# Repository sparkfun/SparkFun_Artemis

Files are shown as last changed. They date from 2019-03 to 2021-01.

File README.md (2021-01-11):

SparkFun Artemis
============================

SparkFun Artemis (https://www.sparkfun.com/products/15332)

[*SparkFun Artemis Module (WRL-15484)*](https://www.sparkfun.com/products/15484)

The Artemis Module from SparkFun is the first product to bridge the market between hobbyists and consumer products. We've exhaustively packaged all the power of a modern microcontroller into a module that is both extremely easy to use but is mass-market ready. 

The flexibility of the Artemis module starts with our [Arduino core](https://github.com/sparkfun/Arduino_Apollo3). You can program and use the Artemis module just like you would an Uno or any other Arduino. Time to first blink is just 5 minutes away! We built the core from the ground up, making it fast and as light weight as possible. 

Next is the module itself. Measuring 10x15mm the Artemis module has all the support circuitry you need to use the fantastic Apollo3 processor in your next project. We're proud to say the SparkFun Artemis module is the first open source hardware module with the design files freely and easily available here (on this repo). We've carefully designed the module so that routing to the module can be done with low-cost 2-layer PCBs with 8mil trace/space. Addtionally, we've released four open-source-hardware example products that act as a starting point for your product.

Made in the USA at SparkFun's Boulder production line the Artemis module is designed for consumer grade products. This truly differentiates the Artemis from its Arduino brethren. Ready to scale your product? The Artemis will grow with you beyond the Uno footprint and Arduino IDE. Tape and reel quantities or the Artemis module are available in addition, the Artemis has an advanced HAL (hardware abstraction layer) allowing users to push the modern Cortex-M4F architecture to its limit. 

This repo contains the design files for the 4-layer PCB. This design is pretty reliant on sophisticated manufacturing tools. We *do not* recommend that you order PCBs and attempt to hand stencil or hand place these components. We hope you can learn from our work and share what you've learned for the next generation of engineers and hackers. 

Repository Contents
-------------------
* **/Artwork** - SVG of laser etching on RF shield
* **/Bootloader** - Tools for loading the Artemis with Ambiq's secure bootloader
* **/Documentation** - Data sheets, additional product information
* **/Hardware** - Eagle design files (.brd, .sch)

Documentation
-------------------
* **[Designing with the SparkFun Artemis](https://learn.sparkfun.com/tutorials/designing-with-the-sparkfun-artemis)** - Layout and design considerations when using the Artemis module.
* **[Artemis Development with Arduino](https://learn.sparkfun.com/tutorials/artemis-development-with-arduino)** - Introduction to the Arduino core for the Artemis Module.
* **[Using SparkFun Edge Board with Ambiq Apollo3 SDK](https://learn.sparkfun.com/tutorials/using-sparkfun-edge-board-with-ambiq-apollo3-sdk)** - Getting set up with the Apollo3 Software Development Kit.

License Information
-------------------

This product is _**open source**_! 

Please review the LICENSE.md file for license information. 

If you have any questions or concerns on licensing, please contact techsupport@sparkfun.com.

Please use, reuse, and modify these files as you see fit. Please maintain attribution to SparkFun Electronics and release any derivative under the same license.

Distributed as-is; no warranty is given.

- Your friends at SparkFun.

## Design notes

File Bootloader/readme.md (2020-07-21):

Artemis Bootloader
==========================

The Artemis module is loaded with two bootloaders: the ASB and SVL. The Ambiq Secure Boot Loader (ASB) resides from 0x00 to 0xC000. This bootloader is physically part of the IC and is configured using the info0 registers. At power up, if the ASB is not activated, it jumps to 0xC000. The SparkFun Variable Bootloader (SVL) resides at 0xC000 and will wait for an incoming serial character. If a character is received, the baud rate will be auto-detected, the SVL will load new code, then jump to the new user code starting at 0x10000. The SVL times out after 50ms.

This directory contains the various binaries that are programmed onto each Artemis module:

* info0_artemis_47_115200.bin - Sets the Ambiq Secure Bootloader (ASB) to 115200bps with boot pin on 47
* artemis_svl.bin - the SparkFun Variable Loader (SVL), starts at 0xC000
* example1_blink.ino.bin - An example sketch to blink the LED. This shows code has been loaded but will be overwritten with new sketches.

The code for the bootloader can be found in the [Apollo3 BSP](https://github.com/sparkfun/SparkFun_Apollo3_AmbiqSuite_BSPs/tree/master/common/examples/artemis_svl).

The bootloader for the Artemis can be upgraded via Arduino using [these instructions](https://learn.sparkfun.com/tutorials/designing-with-the-sparkfun-artemis/all#troubleshooting). It can also be upgraded using the [Artemis Firmware Upload GUI](https://github.com/sparkfun/Artemis-Firmware-Upload-GUI).

The ASB is configured based on the documents from Ambiq (Ambiq calls it the secure bootloader or SBL). See \AmbiqSuite-Rel2.x.x\docs\secure_bootloader\ for how to modify the info0 image. 

* Run the bootloader at 921600bps: --u0 0x1C299c0
* Currently pin 47 is used for BOOTLOAD: --gpio 0x2f
* Bootloader to check if BOOTLOAD pin is high (not low): --gpiolvl 1
* Trim timeout to 2500ms: --wTO 2500

This was used for Artemis v10 module that used pin 47 for boot:

    create_info0.py --valid 1 info0_artemis_47 --pl 1 --u0 0x1C200c0 --u1 0xFFFF3031 --u2 0x2 --u3 0x0 --u4 0x0 --u5 0x0 --main 0xC000 --gpio 0x2f --version 0 --wTO 2500 --gpiolvl 1

We load a conservative 115200bps image into the Ambiq ASB section so that future updates can be applied. The SparkFun Variable Loader is a variable bootloader capable of operating from 115200bps to 921600bps.

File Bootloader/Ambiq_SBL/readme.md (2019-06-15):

Artemis Bootloader
==========================

The Artemis module is loaded with two bootloaders: the SBL and ABL. The Ambiq Secure Boot Loader (SBL) resides from 0x00 to 0xC000. This bootloader is physically part of the IC and is configured using the info0 registers. At power up, if the SBL is not activated, it jumps to 0xC000. The SparkFun Artemis Bootloader (ABL) resides at 0xC000 and will broadcast a character at POR. If the correct response is received, the ABL will negotiate a bootload speed, then jump to user code starting at 0x10000. The ABL times out after 50ms.

This directory contains the various binaries that are programmed onto each Artemis module:

* info0_artemis_47_115200.bin - Sets the SBL to 115200bps with boot pin on 47
* Artemis_Bootloader_v10.bin - the ABL, starts at 0xC000
* example1_blink.ino.bin - An example sketch to blink the LED. This shows code has been loaded but will be overwritten with new sketches.

For more information on the Artemis Bootloader see the Artemis Bootloader sketch in the SparkFun_BL directory in this repo.

The SBL is configured based on the documents from Ambiq. See \AmbiqSuite-Rel2.x.x\docs\secure_bootloader\ for how to modify the SBL/info0 image. 

* Run the bootloader at 921600bps: --u0 0x1C299c0
* Currently pin 47 is used for BOOTLOAD: --gpio 0x2f
* Bootloader to check if BOOTLOAD pin is high (not low): --gpiolvl 1
* Trim timeout to 2500ms: --wTO 2500

This was used for Artemis v10 module that used pin 47 for boot:

    create_info0.py --valid 1 info0_artemis_47 --pl 1 --u0 0x1C200c0 --u1 0xFFFF3031 --u2 0x2 --u3 0x0 --u4 0x0 --u5 0x0 --main 0xC000 --gpio 0x2f --version 0 --wTO 2500 --gpiolvl 1

We load a conservative 115200bps image into the Ambiq SBL section so that future updates can be applied. The SparkFun Artemis Bootloader is a variable bootloader capable of operating from 9600bps to 921600bps.

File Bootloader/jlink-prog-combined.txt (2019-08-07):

//connect to device
device AMA3B1KK-KBR
si SWD
speed 1000
r
sleep 10

//set C runtime environment
wreg MSP, 0x10000100

// erase info0
w4 0x10000000 0             // flash info instance
w4 0x10000004 0xd894e09e    // info 0 key
w4 0x10000008 0xFFFFFFFF    // clear return value
setPC 0x08000085            // call the ROM helper function flash_info_erase_from_sram
g
sleep 50
mem32 0x10000008 1          // dump return value for check

// program info0
w4 0x10000000 0             // flash info instance
w4 0x10000004 0             // offset
w4 0x10000008 0x800         // length in words
w4 0x1000000C 0xd894e09e    // info 0 key
w4 0x10000010 0xFFFFFFFF    // clear return value
loadbin info0_artemis_47_115200.bin 0x10001000     //load the info0 binary into sram
setPC 0x08000061            // call the ROM helper function flash_program_info_area_from_sram
g
sleep 50
mem32 0x10000010 1          // dump return value for check

loadbin artemis_svl.bin 0x0000C000     //load SVL into 0xC000 (end of Ambiq bootloader)

loadbin example1_blink.ino.bin 0x00010000     //load Blink after SVL

// perform software POI
w4 0x40000004 0x1B

// quit
qc

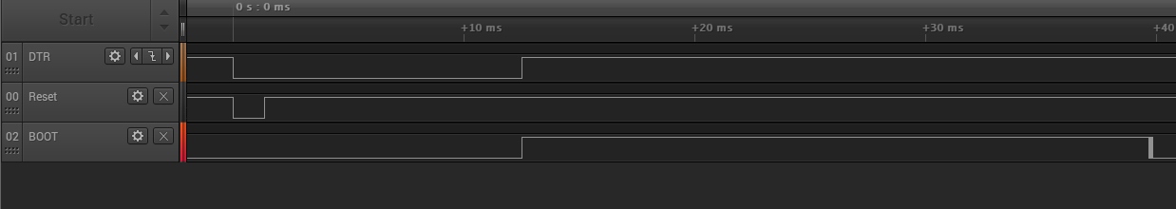
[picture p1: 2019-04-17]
Documents/Auto-Bootload Timing.jpg

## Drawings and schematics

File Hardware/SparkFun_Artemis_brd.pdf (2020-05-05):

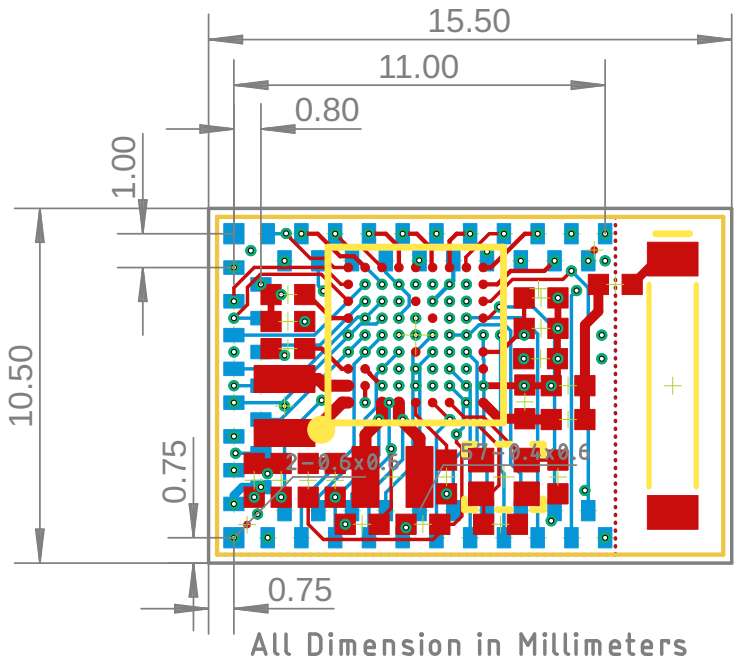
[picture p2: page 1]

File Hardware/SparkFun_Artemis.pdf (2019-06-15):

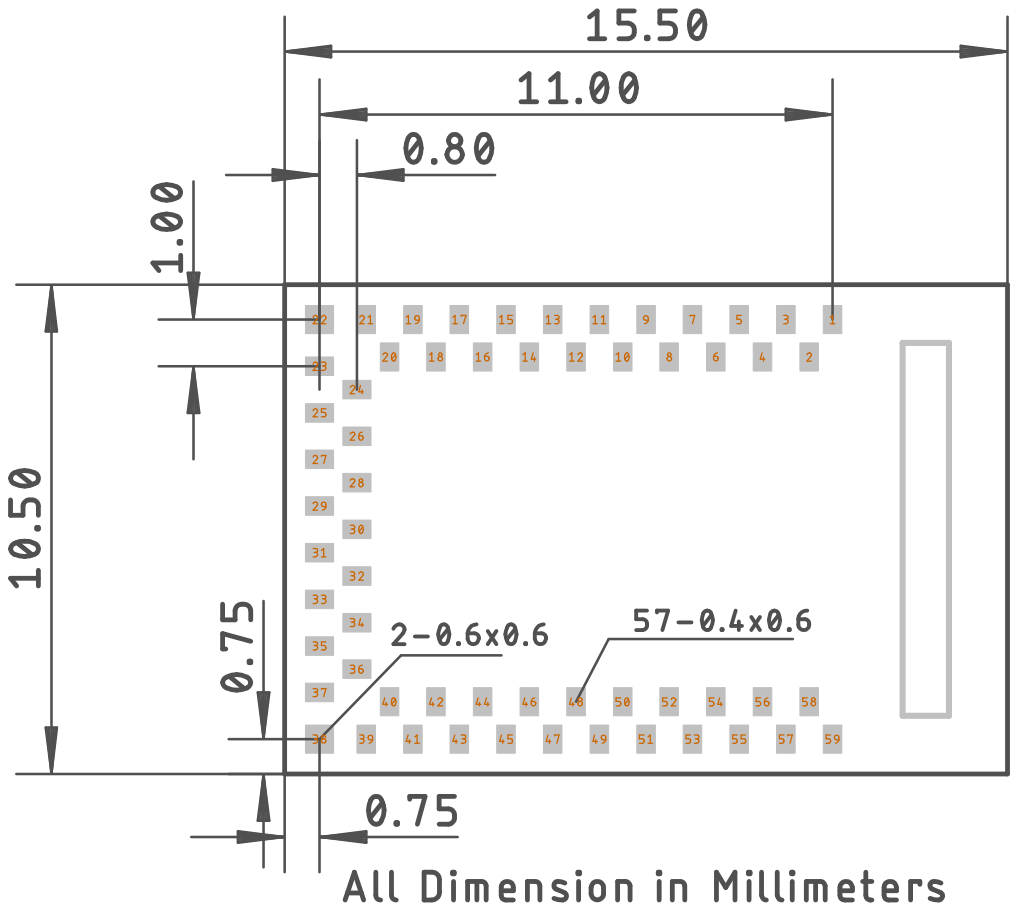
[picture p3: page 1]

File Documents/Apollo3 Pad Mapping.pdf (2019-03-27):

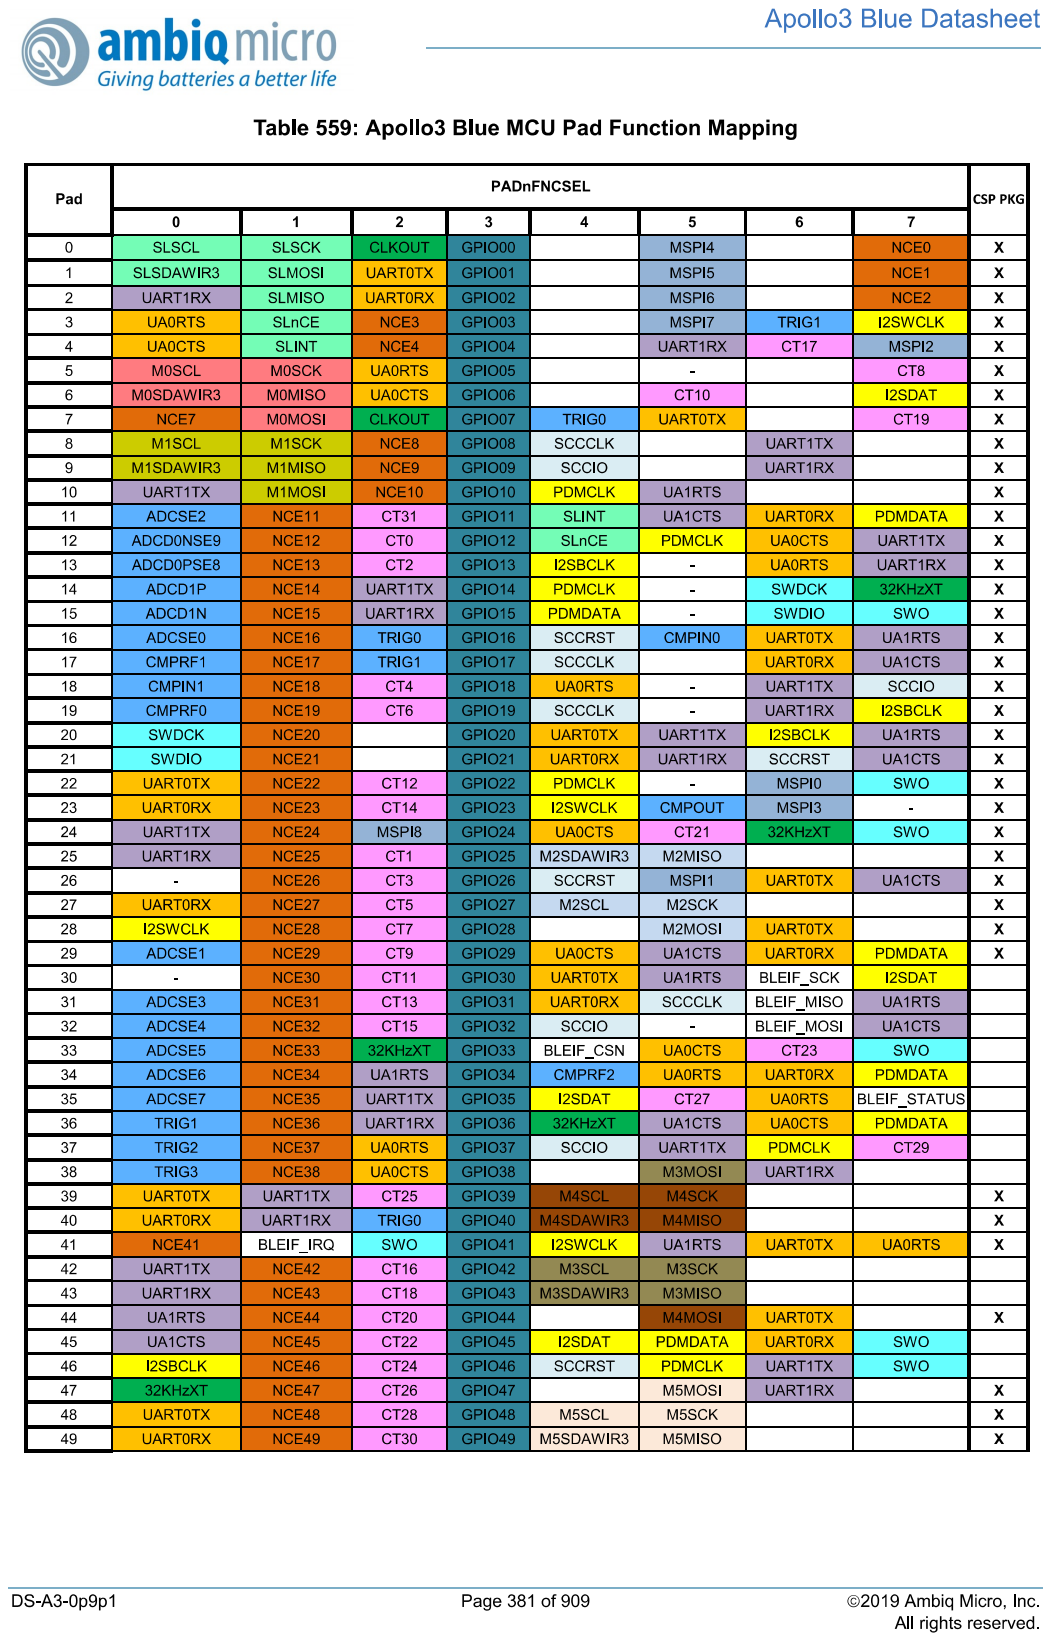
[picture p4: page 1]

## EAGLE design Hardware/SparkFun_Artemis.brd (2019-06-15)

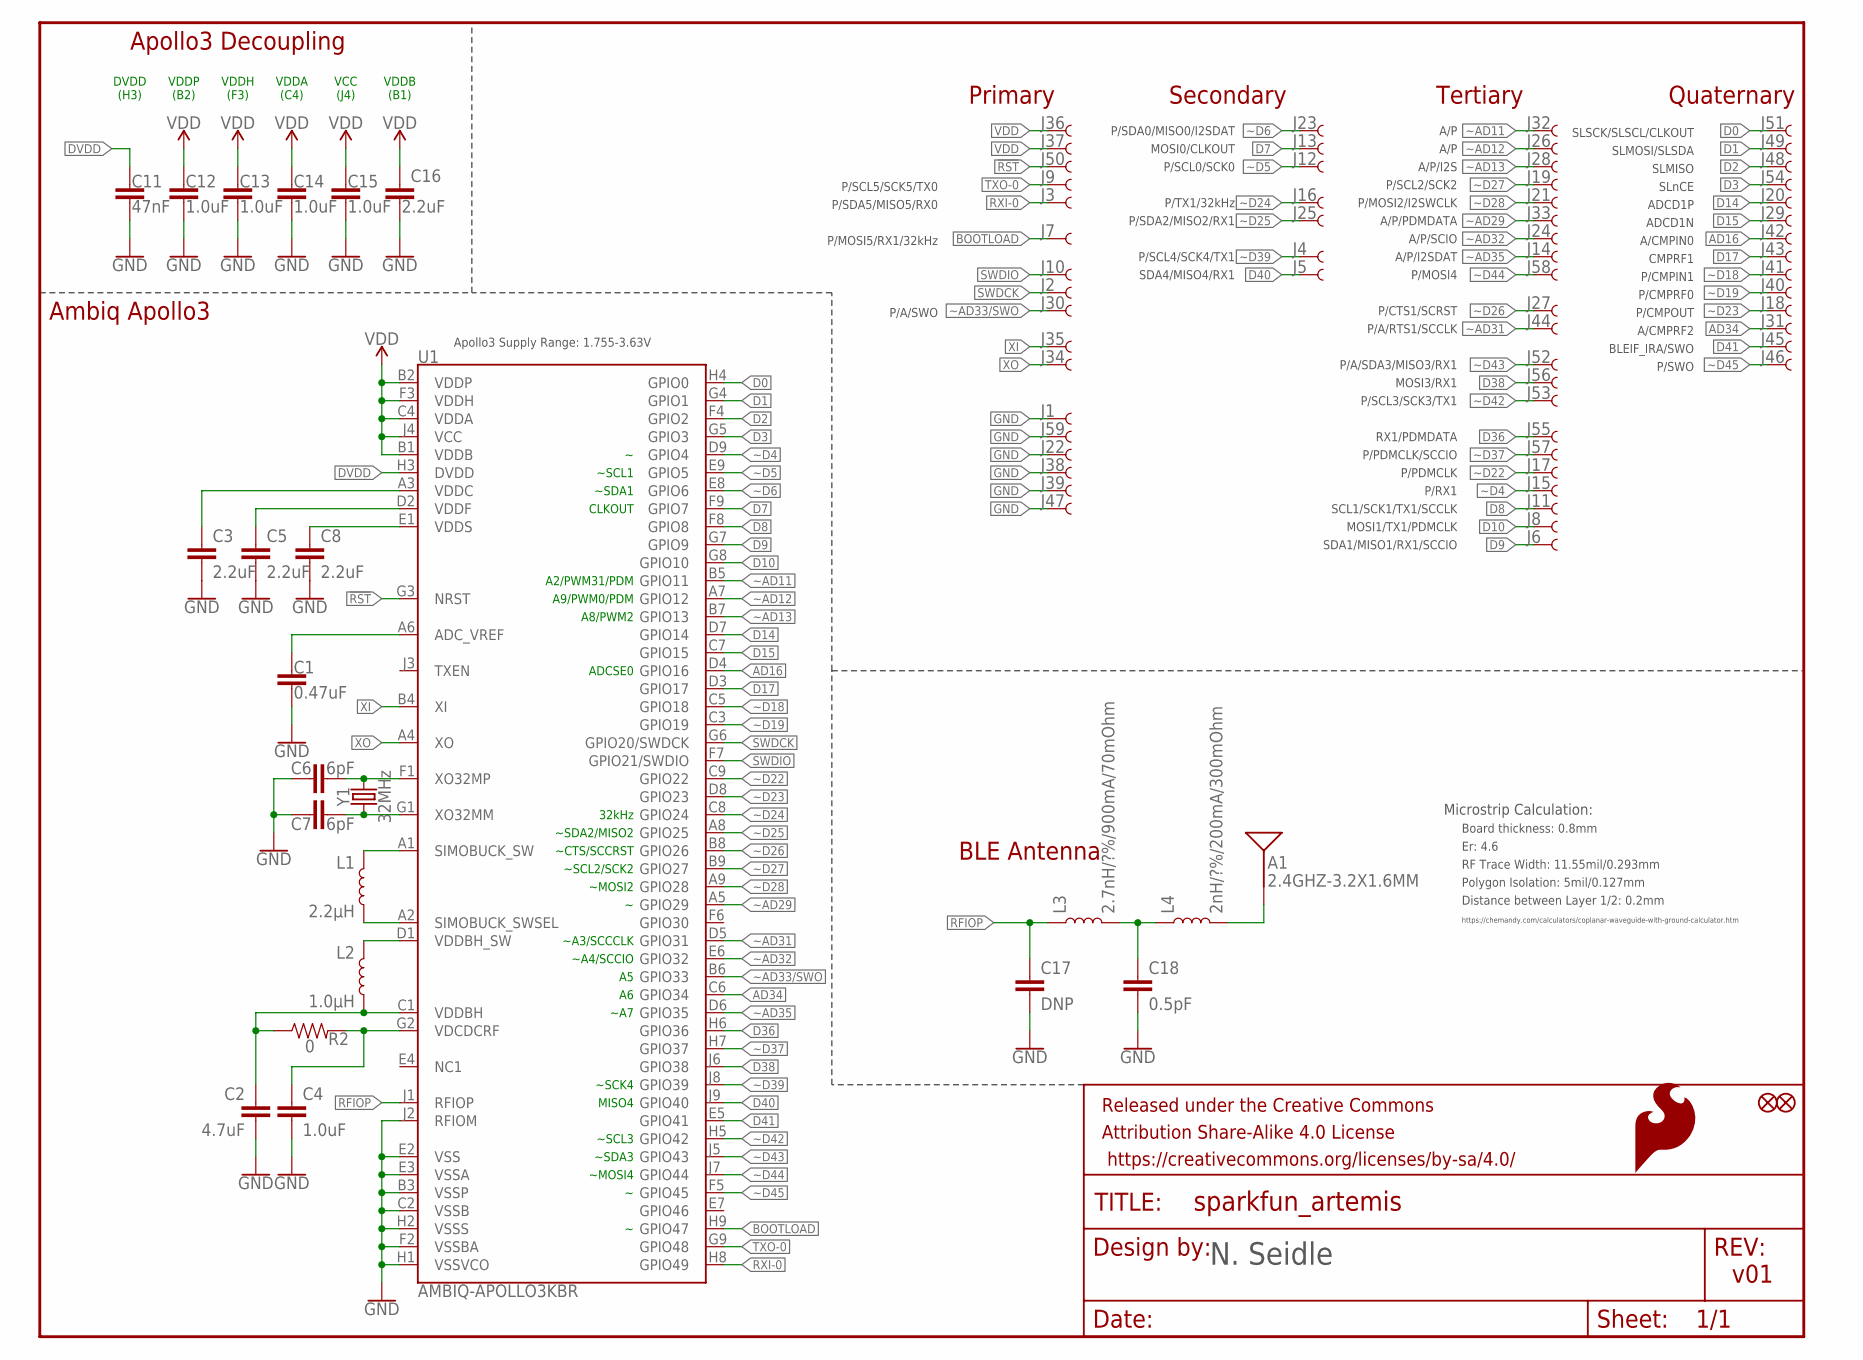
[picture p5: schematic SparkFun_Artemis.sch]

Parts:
A1: 2.4GHZ-3.2X1.6MM; ANT-2.4GHZ-8.0X1.0MM
C1: 0.47uF; 0402-TIGHT
C2: 4.7uF; 0402-TIGHT
C3, C5, C8, C16: 2.2uF; 0402-TIGHT
C4, C12, C13, C14, C15: 1.0uF; 0402-TIGHT
C6, C7: 6pF; 0402-TIGHT
C11: 47nF; 0402-TIGHT
C17: DNP; 0402-TIGHT
C18: 0.5pF; 0402-TIGHT
FD3, FD4: FIDUCIAL0.2MM; FIDUCIAL-0.2MM
FRAME1: FRAME-LETTER; CREATIVE_COMMONS
J1, J2, J3, J4, J5, J6, J7, J8, J9, J10, J11, J12, J13, J14, J15, J16, J17, J18, J19, J20, J21, J23, J24, J25, J26, J27, J28, J29, J30, J31, J32, J33, J34, J35, J36, J37, J39, J40, J41, J42, J43, J44, J45, J46, J47, J48, J49, J50, J51, J52, J53, J54, J55, J56, J57, J58, J59: PAD.4X.6; MODULE_PAD
J22, J38: PAD.35X.35; MODULE_MINI_PAD
L1: 2.2μH; 0805-WIDE
L2: 1.0μH; 0805-WIDE
L3: 2.7nH/?%/900mA/70mOhm; 0402-TIGHT
L4: 2nH/?%/200mA/300mOhm; 0402-TIGHT
LOGO1: SFE_LOGO_FLAME.05_INCH_INTERNAL; SFE_LOGO_FLAME_INTERNAL_0.05
R2: 0; 0402-TIGHT
U1: AMBIQ-APOLLO3KBR; BGA-81-5X5MM
Y1: 32MHz; CRYSTAL-SMD-2.0X1.6MM

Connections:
!RST: J50.1, U1.G3 (NRST)
AD16: J42.1, U1.D4 (GPIO16)
AD34: J31.1, U1.C6 (GPIO34)
ADC_VREF: C1.1, U1.A6 (ADC_VREF)
BOOTLOAD: J7.1, U1.H9 (GPIO47)
D0: J51.1, U1.H4 (GPIO0)
D1: J49.1, U1.G4 (GPIO1)
D2: J48.1, U1.F4 (GPIO2)
D3: J54.1, U1.G5 (GPIO3)
D7: J13.1, U1.F9 (GPIO7)
D8: J11.1, U1.F8 (GPIO8)
D9: J6.1, U1.G7 (GPIO9)
D10: J8.1, U1.G8 (GPIO10)
D14: J20.1, U1.D7 (GPIO14)
D15: J29.1, U1.C7 (GPIO15)
D17: J43.1, U1.D3 (GPIO17)
D36: J55.1, U1.H6 (GPIO36)
D38: J56.1, U1.J6 (GPIO38)
D40: J5.1, U1.J9 (GPIO40)
D41: J45.1, U1.E5 (GPIO41)
DVDD: C11.1, U1.H3 (DVDD)
GND: C1.2, C2.2, C3.2, C4.2, C5.2, C6.1, C7.1, C8.2, C11.2, C12.2, C13.2, C14.2, C15.2, C16.2, C17.2, C18.2, J1.1, J22.1, J38.1, J39.1, J47.1, J59.1, U1.B3 (VSSP), U1.C2 (VSSB), U1.E2 (VSS), U1.E3 (VSSA), U1.F2 (VSSBA), U1.H1 (VSSVCO), U1.H2 (VSSS), U1.J2 (RFIOM)
unnamed: A1.FEED, L4.2
unnamed: C7.2, U1.G1 (XO32MM), Y1.1
unnamed: C6.2, U1.F1 (XO32MP), Y1.3 (2)
unnamed: C18.1, L3.2, L4.1
RFIOP: C17.1, L3.1, U1.J1 (RFIOP)
RXI-0: J3.1, U1.H8 (GPIO49)
SIMBUCK_SWSEL: L1.2, U1.A2 (SIMOBUCK_SWSEL)
SIMOBUCK_SW: L1.1, U1.A1 (SIMOBUCK_SW)
SWDCK: J2.1, U1.G6 (GPIO20/SWDCK)
SWDIO: J10.1, U1.F7 (GPIO21/SWDIO)
TXO-0: J9.1, U1.G9 (GPIO48)
VDCDCRF: C4.1, R2.2, U1.G2 (VDCDCRF)
VDD: C12.1, C13.1, C14.1, C15.1, C16.1, J36.1, J37.1, U1.B1 (VDDB), U1.B2 (VDDP), U1.C4 (VDDA), U1.F3 (VDDH), U1.J4 (VCC)
VDDBH: C2.1, L2.2, R2.1, U1.C1 (VDDBH)
VDDBH_SW: L2.1, U1.D1 (VDDBH_SW)
VDDC: C3.1, U1.A3 (VDDC)
VDDF: C5.1, U1.D2 (VDDF)
VDDS: C8.1, U1.E1 (VDDS)
XI: J35.1, U1.B4 (XI)
XO: J34.1, U1.A4 (XO)
~AD11: J32.1, U1.B5 (GPIO11)
~AD12: J26.1, U1.A7 (GPIO12)
~AD13: J28.1, U1.B7 (GPIO13)
~AD29: J33.1, U1.A5 (GPIO29)
~AD31: J44.1, U1.D5 (GPIO31)
~AD32: J24.1, U1.E6 (GPIO32)
~AD33/SWO: J30.1, U1.B6 (GPIO33)
~AD35: J14.1, U1.D6 (GPIO35)
~D4: J15.1, U1.D9 (GPIO4)
~D5: J12.1, U1.E9 (GPIO5)
~D6: J23.1, U1.E8 (GPIO6)
~D18: J41.1, U1.C5 (GPIO18)
~D19: J40.1, U1.C3 (GPIO19)
~D22: J17.1, U1.C9 (GPIO22)
~D23: J18.1, U1.D8 (GPIO23)
~D24: J16.1, U1.C8 (GPIO24)
~D25: J25.1, U1.A8 (GPIO25)
~D26: J27.1, U1.B8 (GPIO26)
~D27: J19.1, U1.B9 (GPIO27)
~D28: J21.1, U1.A9 (GPIO28)
~D37: J57.1, U1.H7 (GPIO37)
~D39: J4.1, U1.J8 (GPIO39)
~D42: J53.1, U1.H5 (GPIO42)
~D43: J52.1, U1.J5 (GPIO43)
~D44: J58.1, U1.J7 (GPIO44)
~D45: J46.1, U1.F5 (GPIO45)

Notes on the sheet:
DVDD (H3)
VDDP (B2)
VDDH (F3)
VDDA (C4)
VCC (J4)
VDDB (B1)
ADCSE0
A2/PWM31/PDM
~A3/SCCCLK
~SCL3
~SDA3
~A4/SCCIO
~A7
v01
Apollo3 Supply Range: 1.755-3.63V
Ambiq Apollo3
Apollo3 Decoupling
BLE Antenna
A9/PWM0/PDM
A8/PWM2
~CTS/SCCRST
~SDA2/MISO2
~SCL2/SCK2
~MOSI2
~MOSI4
Primary
Secondary
Tertiary
~SCL1
~SDA1
CLKOUT
32kHz
~SCK4
MISO4
N. Seidle
Distance between Layer 1/2: 0.2mm
Microstrip Calculation:
Board thickness: 0.8mm
Er: 4.6
RF Trace Width: 11.55mil/0.293mm

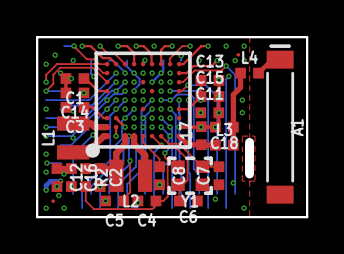
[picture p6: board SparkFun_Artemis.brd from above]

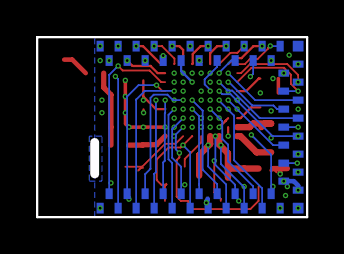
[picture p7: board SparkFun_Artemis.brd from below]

Board: 4 copper layers, 15.0 x 10.0 mm, 87 parts (59 on the bottom side), 68 nets.

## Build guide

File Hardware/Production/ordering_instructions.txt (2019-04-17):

panel size, 107x98mm
PCB thickness, 0.8mm
number of layers, 4
soldermask color, Red
silkscreen color, White
oz copper, 1oz
finish, ENIG / RoHS
stencils, top
pcs per panel, 48
min trace width, 0.101600mm / 0.004000in
min drill size, 0.150000mm / 0.005906in
filename to layer stackup 1/2/3/4: GTL, GL2, GL3, GBL
Drill file 0102: Connects GTL+GL2
Drill file 0116: Connects GTL+GBL
Drill file 1516: Connects GL3+GBL

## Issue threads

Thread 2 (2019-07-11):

Bootloader Timing Dependency

oclyke, 2019-07-11:
## Intro
Some initial investigation indicates that there may be a dependency on timing of the accompanying Python script on the host computer. On Windows the timing is sufficient to successfully bootload, but on MacOSX (and possibly Linux) the timing causes a failure when using the Artemis Bootloader.

## Background
- Most testing of the Artemis Bootloader (also called "SparkFun Variable Loader" or SVL) has occurred on Windows machines.
- Deploying the [Apollo3 Arduino Core](https://github.com/sparkfun/Arduino_Apollo3) increased the amount of testing that could be done on Mac and Linux, many thanks to helpful users
- This issue was found after looking into this issue: [Upload issue SparkFun Edge](https://github.com/sparkfun/Arduino_Apollo3/issues/21)

## Details
- Differences between Windows and MacOSX (and perhaps Linux) within SVL Python script: (Can be observed in Logic LA captures [SecondResetCapture](https://github.com/sparkfun/SparkFun_Artemis/files/3383197/SecondResetCapture.logicdata.zip) (Mac) and [GoodWindowsRef](https://github.com/sparkfun/SparkFun_Artemis/files/3383194/GoodWindowsRef.zip) (Windows)
    - *Time to switch USB-serial baud rate.* (Windows: ~15 ms, MacOSX: ~37 ms)
    - *Control lines toggle on change baud rate.* (Windows: no control toggle on baud change, MacOSX: Control lines toggle causing another reset after changing baud rate)

## Explanation
The differences above cause the bootload process to fail, each for their own reasons.
- The time to switch can cause the bootloader to hang if the computer does not send"BL_COMMAND_COMPUTER_READY" before the bootloader sends "BL_COMMAND_NEXT_FRAME"
- The second reset will wreak havoc on the baud rate negotiation by losing volatile baud rate data.

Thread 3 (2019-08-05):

Rust support

freiguy1, 2019-08-05:
I'm not sure if this is is the right spot for this issue. Let me know where I can move it if not.

I believe Rust support on these boards would be a killer feature.  This would allow programmers to use this 21st century language that is much safer, friendlier, and just as fast as c/c++. It also compiles down to bytecode for the microcontroller so no runtime is needed.

I'm not sure how much work would be needed. There's a chance that it wouldn't be much! Heck, I'm running rust on a Cortex M3 at home right now. There's a whole rust-embedded team working for Cortex M4 support, and many boards are already supported. https://github.com/rust-embedded/wg

Also I found this repo which looks like it has Apollo3 peripheral support in rust: https://github.com/rgcottrell/ambiq-apollo3-pac

Thanks for taking this into consideration! I don't want to sound too sensational, but I can't help it: I think if Sparkfun came out as a leader in embedded-rust, it could be the start of an embedded software revolution. I think Rust on silicon is the next big stage that the embedded community will find. In addition to the benefits listed above using Rust would also add a great package manager, debugging capabilities, unit testing, and modern code semantics (for example: higher order functions (`myList.map(|item| item * 2)`) and algebraic data types). Not to forget, I think Rust support on the Artemis boards would also be a good business move for Sparkfun.

mardab, 2019-12-09:
+1, but I have no idea what's holding the support back, pac crate exists and the chip is fairly standard M4F, what are we missing?

freiguy1, 2019-12-09:
Maybe someone only needs to try it! A HAL layer would be great to abstract from the registers and bits, but that's not totally necessary to get up and running. I thought about taking on a HAL myself, but want to finish a couple other projects currently.

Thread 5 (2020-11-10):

examples and wrappers for using core FFT algorithms

jerabaul29, 2020-11-10:
Hi,

First, thank you for releasing this very exciting board.

This issue may be better posted at another place; if this is the case, please just let me know and I will move it.

I see that the processor supports taking FFTs in an effective way:

https://github.com/sparkfun/OpenLog_Artemis_Geophone_Logger/blob/master/Firmware/OpenLog_Artemis_Geophone_Logger/Geophone.ino

However, there is still quite a bit of low level "obfuscation" for n00bs like me to use it.

Would it be possible to get a few wrappers that provide a dead simple interface to take a FFT on some data, for example something like:

```c++
constexpr size_t fft_size = 512;

class FFT_Analyzer{
  public:
    float32_t timeseries_in[fft_size];
    float32_t fft_out[fft_size];
    void perform_fft(void);
};
```

or something like this, which would simply perform the fft analysis from the timeseries_in into the fft_out, with documentation of what the admissible buffer sizes are, and other possible tricks and tips?

Many thanks in advance!

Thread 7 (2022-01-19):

Negative Voltage on Boot Pin

derekpickell, 2022-01-19:
Hello,

Let me know if this is not the best place for this question and I will move it! Haven't gotten any feedback on the sparkfun forum so thought I should try here:

I noticed that the bootloader circuit temporarily drives the BOOT pin to -3.3V. Nowhere in the Apollo3 datasheet do I see any mention of being able to expose pins to negative voltage, and yet the boards seem to work fine! Just looking for confirmation that this is OK. Thank you!

nseidle, 2022-01-19:
[RedBoard-Artemis](https://cdn.sparkfun.com/assets/4/5/a/3/e/RedBoardArtemisSchematic.pdf) bootloader circuit:

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

Can you share a screenshot of the measurements you took? I remember doing the testing of the BL circuit and I never saw a negative voltage.

derekpickell, 2022-01-19:
Here's how I setup my breadboard:
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

Since I'm planning on uploading code only via a USB to Serial converter, I haven't included the DTR bus (although it's the same circuit), and the RESET is represented by the switch.

Here's the oscilloscope photo: the negative spike is when I manually ground RESET, and the positive is when I unground it.
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

Really appreciate the help!

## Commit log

2019-03-27 Moar pins
    [SparkFun_Artemis.brd]
2019-03-28 Add C9 pad. Add FP for Artemis module.
    [SparkFun_Artemis.brd, SparkFun_Artemis.sch]
2019-03-28 Fix pad slightly off center.
    [SparkFun_Artemis.brd]
2019-03-29 Moving pads to bDocu. Changing layer colors.
    [SparkFun_Artemis.brd, SparkFun_Artemis.sch]
2019-03-30 Changing RF trace width to 11.55mil
    [SparkFun_Artemis-Panel.GBL, SparkFun_Artemis-Panel.GBO, SparkFun_Artemis-Panel.GBS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]
2019-04-04 Change chip antenna. Fixed shield running into trace. Post design review.
    [SparkFun_Artemis.brd, SparkFun_Artemis.sch]
2019-04-15 Antenna change
    [SparkFun_Artemis.brd]
2019-04-15 Going to buried vias
    [SparkFun_Artemis.brd, SparkFun_Artemis.sch]
2019-04-16 Buried via approach. Moar GPIOs!
    [SparkFun_Artemis.brd, SparkFun_Artemis.sch]
2019-04-16 Commit for Quote
    [SparkFun_Artemis-Panel.GBL, SparkFun_Artemis-Panel.GBP, SparkFun_Artemis-Panel.GBS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]
2019-04-17 Add fiducials. Add auto-bootload timing diagram.
    [SparkFun_Artemis.brd, SparkFun_Artemis.sch]
2019-04-17 Submitting for production
    [SparkFun_Artemis.brd, SparkFun_Artemis.sch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]
2019-04-18 Adding new v1 FP of Artemis module
    [SparkFun_Artemis.brd, SparkFun_Artemis.sch]
2019-05-13 Update inductor part # to 1mm height
    [SparkFun_Artemis.brd]
2019-05-28 Adding dimensions
    [SparkFun_Artemis.brd, SparkFun_Artemis.sch]
2019-05-28 Add antenna datasheet. Remove old datasheets.
2019-06-05 Add readme. Clean up repo.
    [SparkFun_Artemis.brd]
2019-06-05 Compress schematic
    [SparkFun_Artemis.brd, SparkFun_Artemis.sch]
2019-06-15 Removing old bootload files. Adding Artemis Bootloader v1.
    [SparkFun_Artemis.brd]
2026-03-07 Add 3D models of the module
    Got this 3D model on the SparkFun forums. Thanks TS-Russel. Wanted to share
    Also I made an STL version for broader compatibility

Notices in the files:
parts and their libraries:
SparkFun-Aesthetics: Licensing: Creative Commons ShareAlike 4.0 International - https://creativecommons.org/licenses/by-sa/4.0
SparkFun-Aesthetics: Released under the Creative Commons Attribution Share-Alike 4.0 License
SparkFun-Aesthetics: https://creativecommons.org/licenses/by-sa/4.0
